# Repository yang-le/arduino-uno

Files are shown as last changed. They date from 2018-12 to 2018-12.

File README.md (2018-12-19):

# arduino-uno

## Front

### 3d
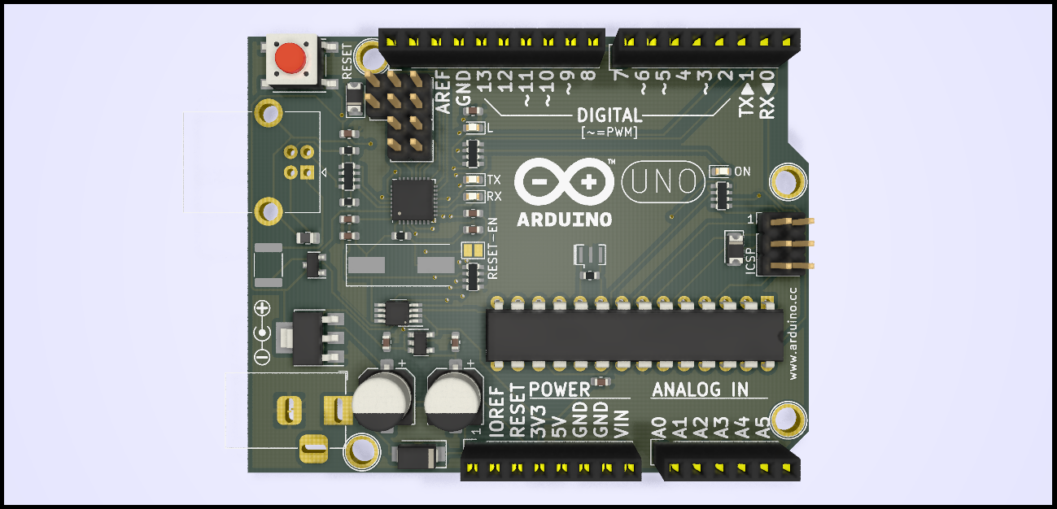
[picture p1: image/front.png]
front3d


### 2d
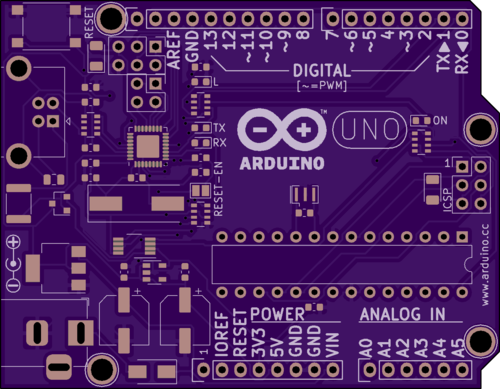
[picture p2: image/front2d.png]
front2d


### Cu
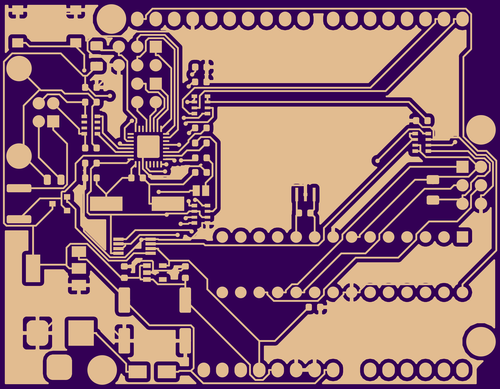
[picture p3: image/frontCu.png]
frontCu


### Pad
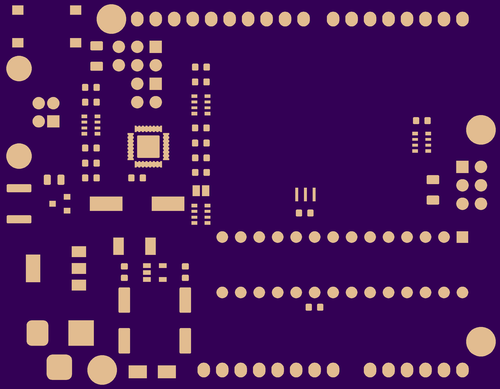
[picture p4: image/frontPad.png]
frontPad


### Silk
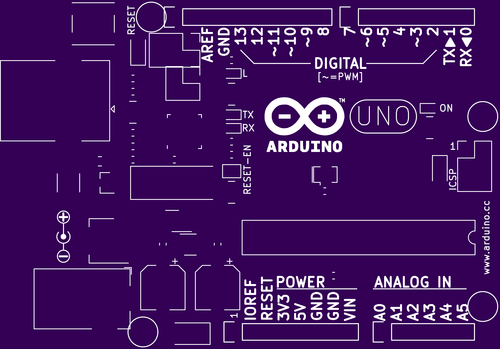
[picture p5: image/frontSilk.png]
frontSilk


## Back

### 3d
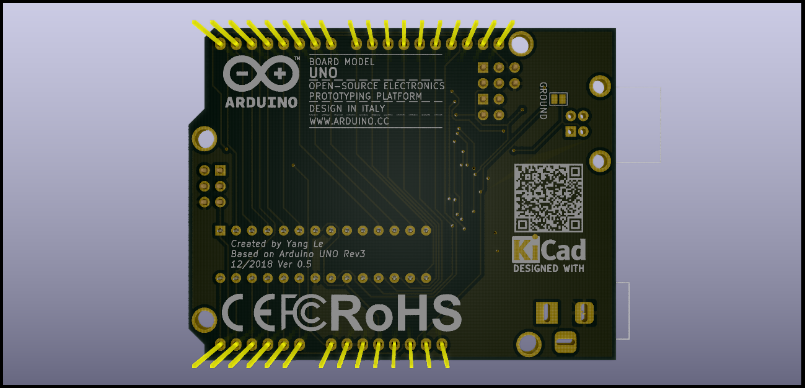
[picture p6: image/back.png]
back3d


### 2d
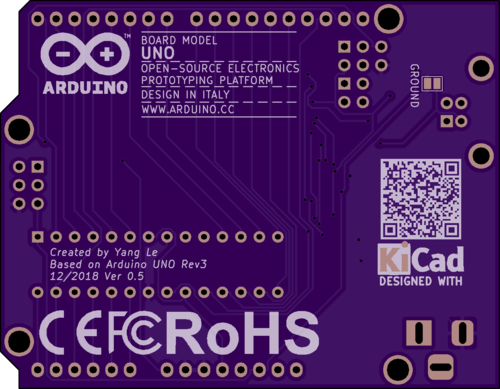
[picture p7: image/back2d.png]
back2d


### Cu
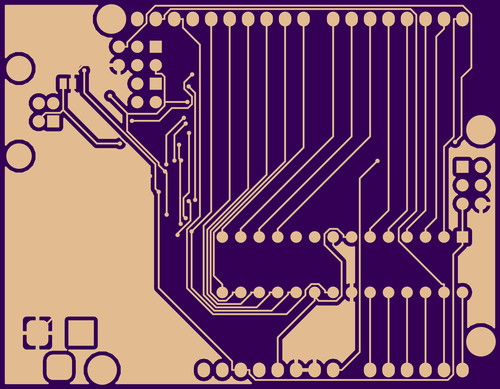
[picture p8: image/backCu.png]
backCu


### Pad
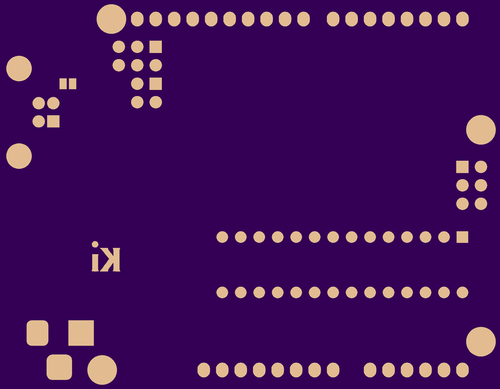
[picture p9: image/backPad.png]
backPad


### Silk
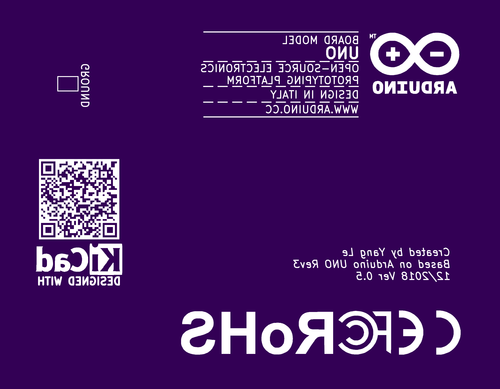
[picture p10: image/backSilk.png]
backSilk


## Misc

### Edge
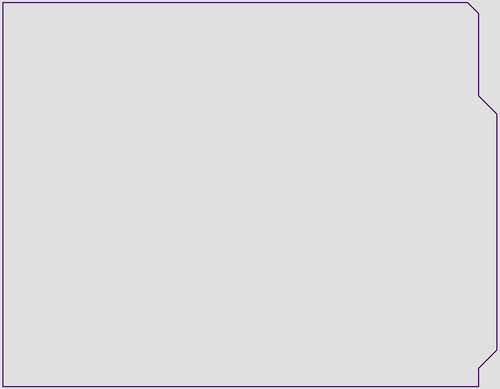
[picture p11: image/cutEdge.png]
cutEdge


### Drill
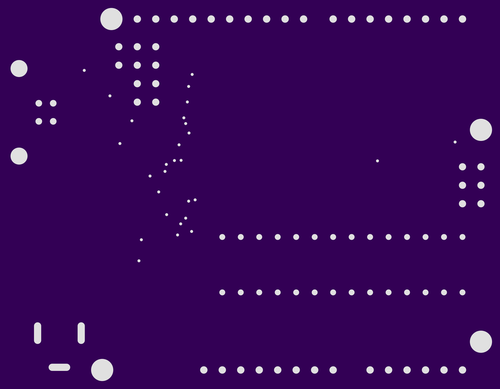
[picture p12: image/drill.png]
drill


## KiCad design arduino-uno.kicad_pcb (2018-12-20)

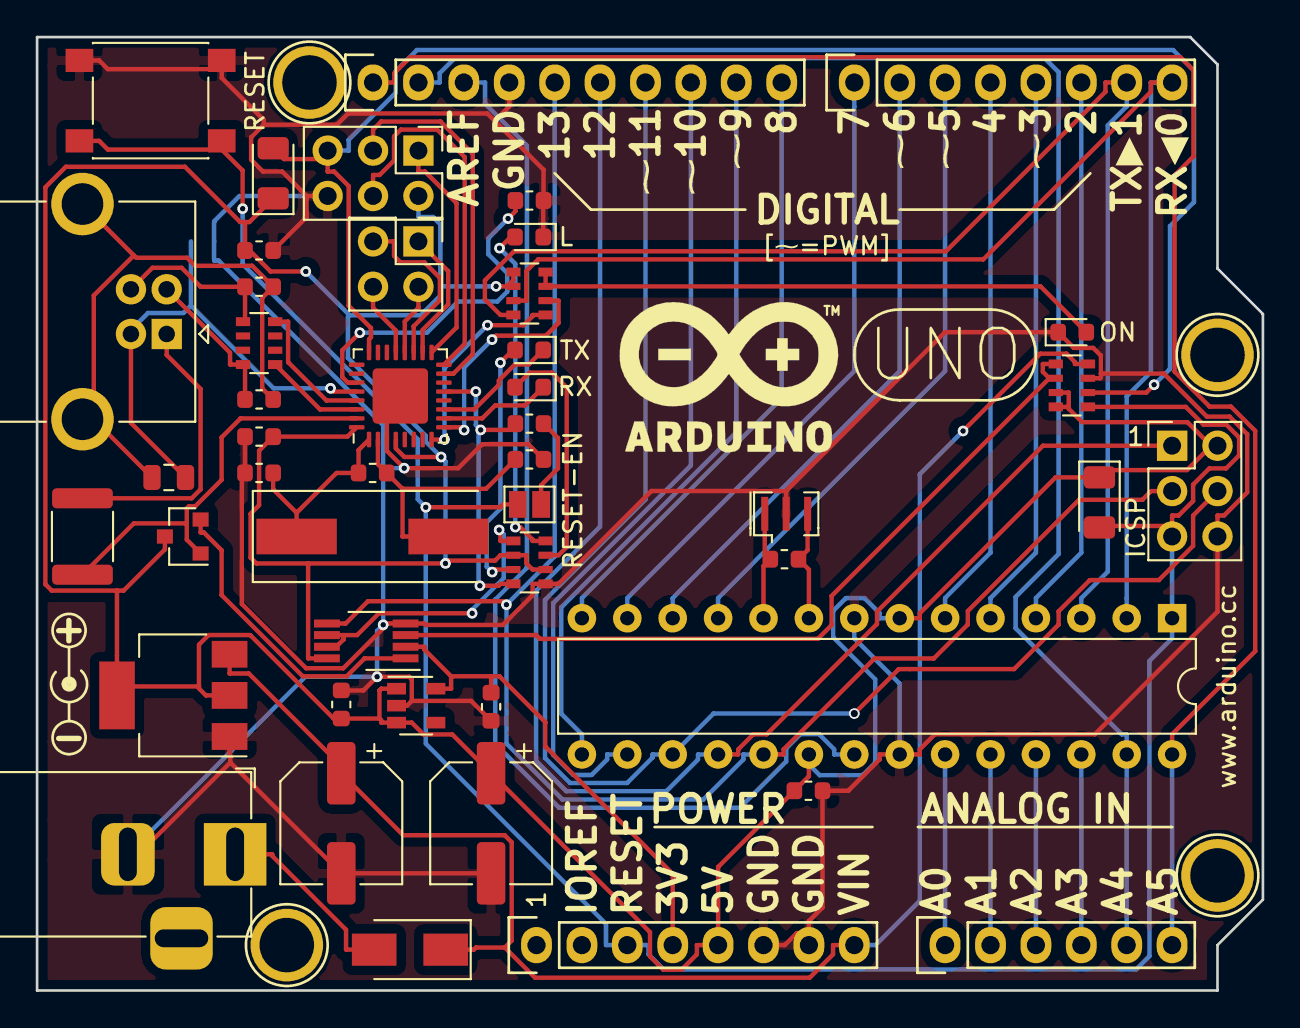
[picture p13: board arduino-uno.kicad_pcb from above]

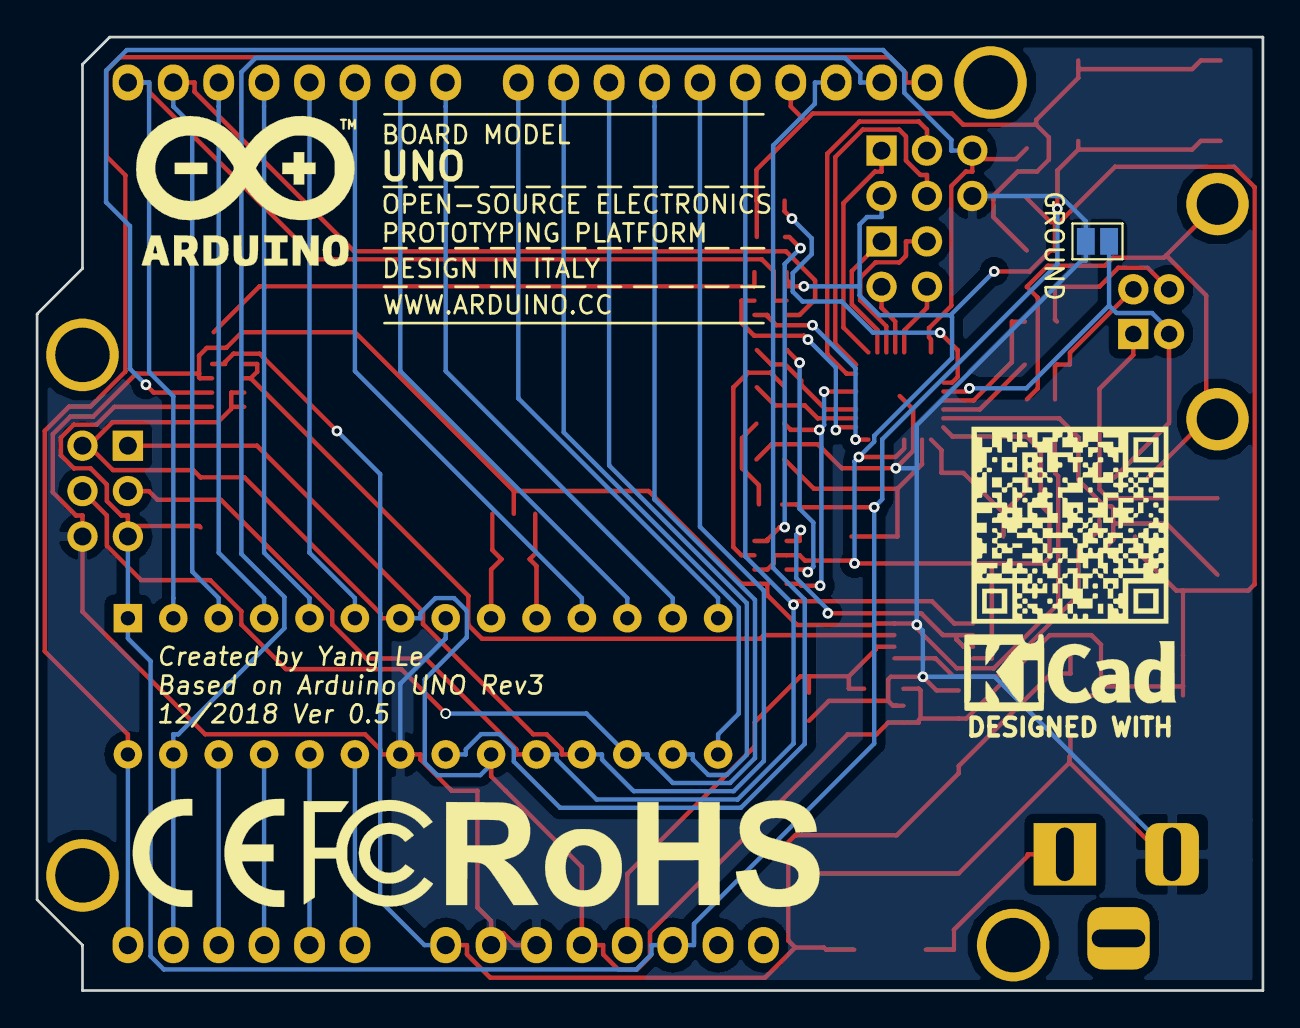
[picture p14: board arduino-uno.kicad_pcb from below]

Board: 2 copper layers, 68.6 x 53.3 mm, 60 parts (7 on the bottom side), 61 nets.

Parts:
C1, C2: 47u; CP_Elec_6.3x5.9
C3, C4, C8, C10, C11: 100n; C_0603_1608Metric
C5, C9: 1u; C_0603_1608Metric
C6, C7: 22p; C_0603_1608Metric
D1: M7; D_SMA
D3, D6: CD1206-S01575; D_1206_3216Metric
F1: MF-MSMF050-2; Fuse_1812_4532Metric
FB1: BLM21; L_0805_2012Metric
G1, G2, G3: LOGO
GROUND: GROUND; SolderJumper-2_P1.3mm_Open_Pad1.0x1.5mm
ICSP: Conn_02x03; PinHeader_2x03_P2.54mm_Vertical
J1: Jack-DC; BarrelJack_Horizontal
J2: USB_B; USB_B_OST_USB-B1HSxx_Horizontal
J3: Conn_02x03; PinHeader_2x03_P2.54mm_Vertical
J4: Conn_02x02; PinHeader_2x02_P2.54mm_Vertical
L: L; LED_0603_1608Metric
ON: ON; LED_0603_1608Metric
P1: Power; Socket_Strip_Arduino_1x08
P2: Analog; Socket_Strip_Arduino_1x06
P3: Digital; Socket_Strip_Arduino_1x10
P4: Digital; Socket_Strip_Arduino_1x08
P5, P6, P7, P8: CONN_01X01; Arduino_1pin
Q1: FDN340P; SOT-23
R1, R2: 1M; R_0603_1608Metric
REF1: Symbol_Barrel_Polarity
REF2: CE-Logo_8.5x6mm_SilkScreen
REF3: FCC-Logo_7.3x6mm_SilkScreen
REF4: RoHS-Logo_6mm_SilkScreen
REF5: KiCAD Logo; Symbol_KiCAD-Logo_CopperAndSilkScreenTop
RESET: RESET; SW_SPST_PTS645
RESET-EN: RESET-EN; SolderJumper-2_P1.3mm_Open_Pad1.0x1.5mm
RN1: 10K; R_Array_Convex_4x0603
RN2, RN4: 1K; R_Array_Convex_4x0603
RN3: 22; R_Array_Convex_4x0603
RV1, RV2: CG0603MLC-05E; R_0603_1608Metric
RX: RX; LED_0603_1608Metric
TX: TX; LED_0603_1608Metric
U1: NCP1117-5.0; SOT-223-3_TabPin2
U2: LMV358IDGKR; VSSOP-8_3.0x3.0mm_P0.65mm
U3: LP2985-3.3; SOT-23-5
U4: ATmega16U2-MU; QFN-32-1EP_5x5mm_P0.5mm_EP3.1x3.1mm
U5: ATmega328P-PU; DIP-28_W7.62mm
Y1: Crystal; Crystal_SMD_HC49-SD
Y2: CSTCE16M0V53-R0; Resonator_SMD_muRata_CSTxExxV-3Pin_3.0x1.1mm

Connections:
+3V3: C5.1, P1.4, U2.2, U3.5
+5V: C2.1, C3.1, C4.1, C8.1, C11.1, D3.1, D6.1, ICSP.2, J3.2, P1.5, Q1.3, RN1.3, RN1.4, RN2.2, RN2.6, RN4.5, RN4.6, U1.2, U2.8, U3.1, U3.3, U4.4, U4.32, U5.7, U5.20
/Main/0(Rx): P4.8, RN4.7, U5.2
/Main/1(Tx): P4.7, RN4.8, U5.3
/Main/2: P4.6, U5.4
/Main/3(**): P4.5, U5.5
/Main/4: P4.4, U5.6
/Main/5(**): P4.3, U5.11
/Main/6(**): P4.2, U5.12
/Main/7: P4.1, U5.13
/Main/8: P3.10, U5.14
/Main/9(**): P3.9, U5.15
/Main/10(**/SS): P3.8, U5.16
/Main/11(**/MOSI): ICSP.4, P3.7, U5.17
/Main/12(MISO): ICSP.1, P3.6, U5.18
/Main/13(SCK): ICSP.3, P3.5, U2.5, U5.19
/Main/A0: P2.1, U5.23
/Main/A1: P2.2, U5.24
/Main/A2: P2.3, U5.25
/Main/A3: P2.4, U5.26
/Main/A4(SDA): P2.5, P3.2, U5.27
/Main/A5(SCL): P2.6, P3.1, U5.28
/Main/AREF: P3.3, U5.21
/Main/DTR: C10.2, RN2.4, U4.13
/Main/M8RXD: RN4.2, U4.9
/Main/M8TXD: RN4.1, U4.8
/Main/Reset: D6.2, ICSP.5, P1.3, RESET.1, RESET-EN.1, RN1.5, U5.1
/Main/VIN: C1.1, D1.1, P1.8, RN1.8, U1.3
/Power/USBVCC: F1.1, Q1.1, U4.31
/USB/MISO2: J3.1, U4.17
/USB/MOSI2: J3.4, U4.16
/USB/SCK2: J3.3, U4.15
GND: C1.2, C2.2, C3.2, C4.2, C5.2, C6.2, C7.2, C8.2, C9.2, C11.2, GROUND.2, ICSP.6, J1.2, J3.6, L.1, ON.1, P1.6, P1.7, P3.4, RESET.2, RN1.7, RN2.5, U1.1, U2.4, U3.2, U4.3, U4.33, U5.8, U5.22, Y2.2
unnamed: C6.1, R1.1, U4.1, Y1.1
unnamed: C7.1, R1.2, U4.2, Y1.2
unnamed: C9.1, U4.27
unnamed: C10.1, RESET-EN.2
unnamed: D1.2, J1.1
unnamed: ON.2, RN4.3, RN4.4
unnamed: D3.2, J3.5, RN1.6, U4.24
unnamed: TX.1, U4.11
unnamed: RN2.3, TX.2
unnamed: RX.1, U4.10
unnamed: RN2.7, RX.2
unnamed: L.2, RN2.8
unnamed: F1.2, J2.1
unnamed: FB1.1, J2.5, RV1.2, RV2.2
unnamed: FB1.2, GROUND.1, J2.4, U4.28
unnamed: J2.2, RN3.8, RV2.1
unnamed: J2.3, RN3.5, RV1.1
unnamed: J4.1, U4.18
unnamed: J4.2, U4.20
unnamed: J4.3, U4.19
unnamed: J4.4, U4.21
unnamed: Q1.2, U2.1
unnamed: R2.1, U5.9, Y2.3
unnamed: R2.2, U5.10, Y2.1
unnamed: RN1.1, RN1.2, U2.3
unnamed: RN2.1, U2.6, U2.7
unnamed: RN3.1, U4.30
unnamed: RN3.4, U4.29

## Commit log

2018-12-16 place finish
    [arduino-uno.kicad_pcb, main.sch]
2018-12-16 route finish
    [arduino-uno.kicad_pcb, main.sch, usb.sch]
2018-12-18 add logos
    [arduino-uno.kicad_pcb]
2018-12-19 replace two Caps
    [arduino-uno.kicad_pcb]
2018-12-20 ready to fab
    [arduino-uno-B.CrtYd.gbr, arduino-uno-B.Cu.gbr, arduino-uno-B.Fab.gbr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]
2018-12-20 add 3d shapes for usb & crystal
    [arduino-uno.kicad_pcb]
